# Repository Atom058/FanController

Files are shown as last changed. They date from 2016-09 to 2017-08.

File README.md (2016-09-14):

#About this project
This project aims to create a PC fan controller, based on the Arduino / Atmel frameworks.

#Fuse bits

Low:	0xF7
High:	0xD8
Ext:	0x04

#Pins with input/output

*) OCR0A: Fan1PWM
*) OCR0B: Fan2PWM
*) OCR1A: Fan3PWM
*) OCR1B: Fan4PWM
*) OCR2A: Fan5PWM
*) ADC0: FanCurrentSense1
*) ADC1: FanCurrentSense2
*) ADC2: FanCurrentSense3
*) ADC3: FanCurrentSense4
*) ADC4: FanCurrentSense5
*) PD0: SER
*) PD1: SRCLK
*) PD2: SRCLR
*) PD3: RCLK
*) PD4: OE
*) XTAL1: Crystal
*) XTAL2: Crystal
*) PB4: Switch Left
*) PB5: Switch Right
*) PB0: Switch press

##Unconnected pins
*) PC5
*) PD7

#Fuses

CKSEL0: 1
CKSEL1: 1
CKSEL2: 1
CKSEL3: 0

SUT0: 0
SUT1: 1

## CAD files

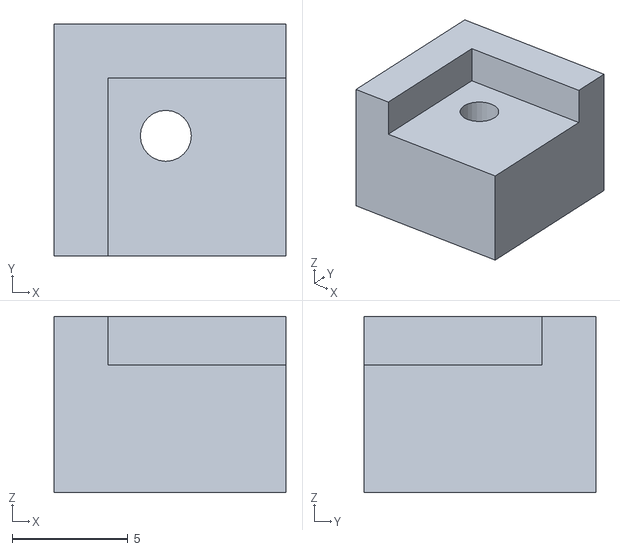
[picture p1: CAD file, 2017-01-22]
Fan controller schematics/3D drawing/Back support.stl
10.0 x 10.0 x 7.60

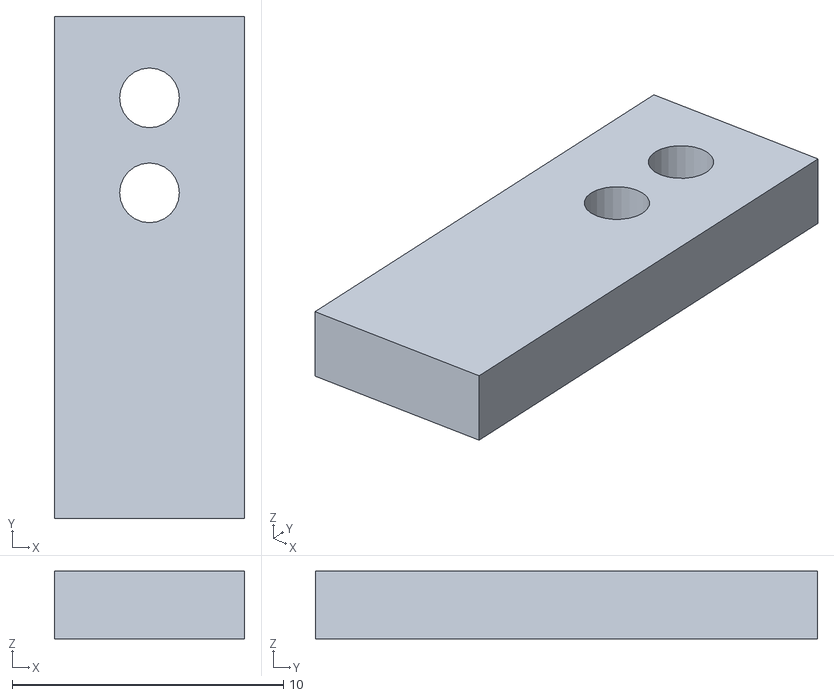
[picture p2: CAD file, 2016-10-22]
Fan controller schematics/3D drawing/Rotary Encoder - endstop attachement v1.stl
7.00 x 18.5 x 2.50

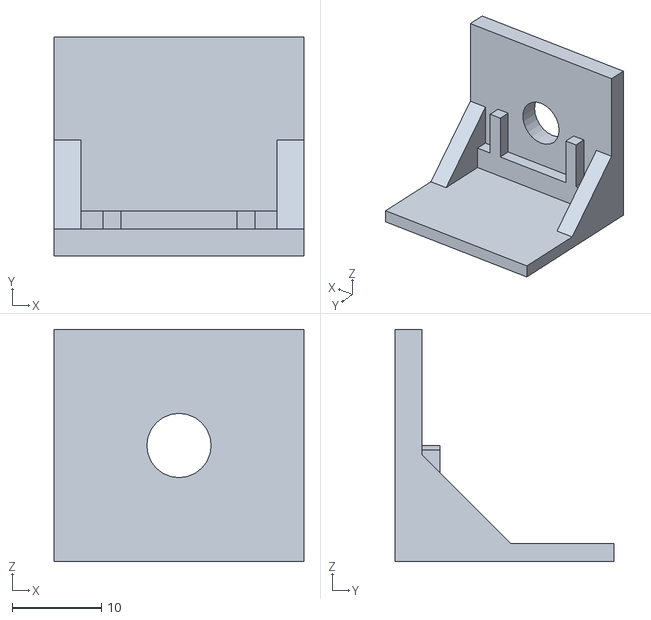
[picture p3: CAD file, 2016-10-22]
Fan controller schematics/3D drawing/Rotary Encoder - wagon v1.stl
28.0 x 24.5 x 26.0

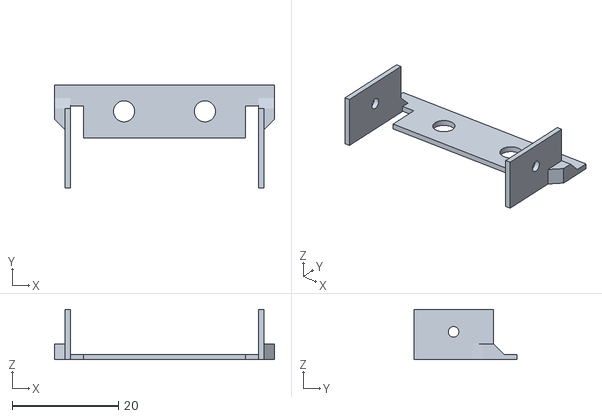
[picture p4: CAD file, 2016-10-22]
Fan controller schematics/3D drawing/Rotary encoder - click support B v1.stl
41.5 x 19.5 x 9.50

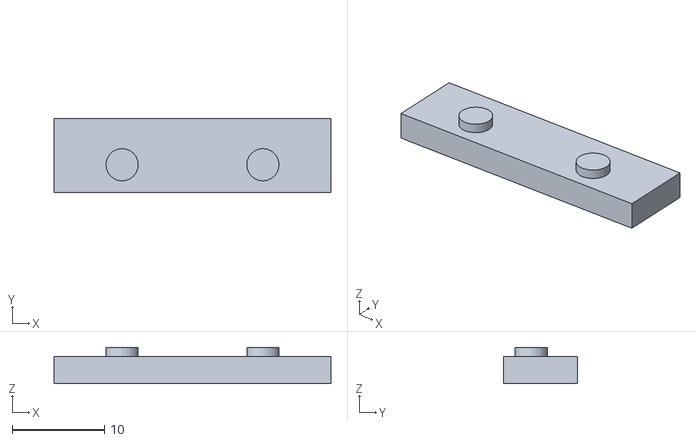
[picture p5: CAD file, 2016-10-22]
Fan controller schematics/3D drawing/Rotary encoder - click support A v1.stl
30.0 x 8.00 x 3.90

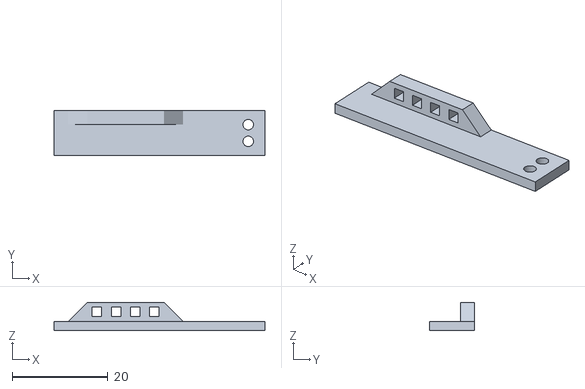
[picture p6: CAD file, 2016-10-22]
Fan controller schematics/3D drawing/Rotary Encoder - endstop v2.stl
44.1 x 9.50 x 5.90

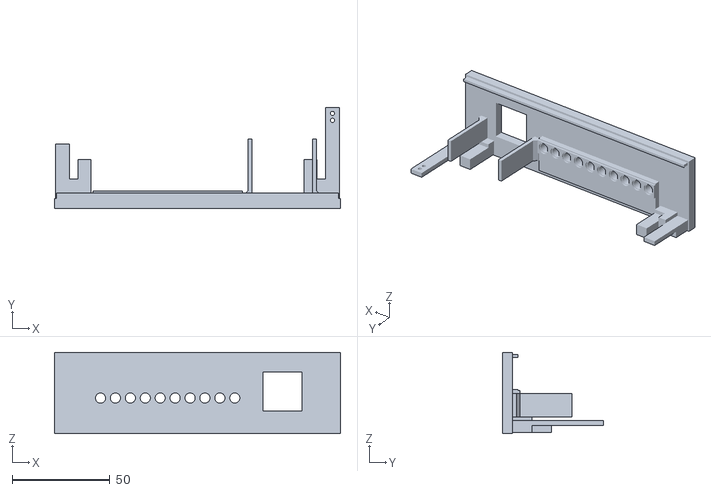
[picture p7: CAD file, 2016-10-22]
Fan controller schematics/3D drawing/Fan controller Front v1.stl
146.1 x 51.5 x 41.5

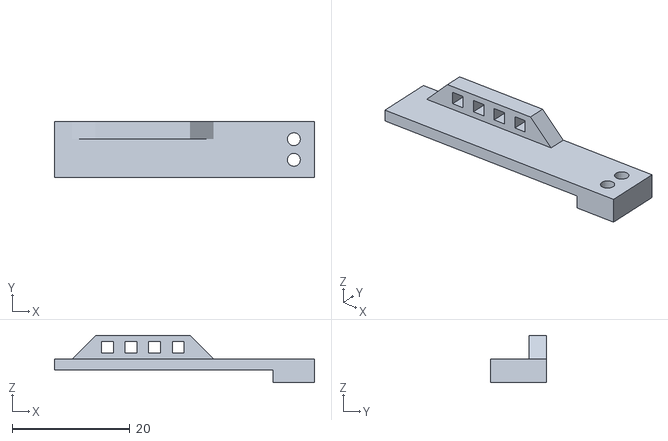
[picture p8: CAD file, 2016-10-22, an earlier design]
Fan controller schematics/3D drawing/Rotary Encoder - endstop v1.stl
44.1 x 9.50 x 8.00

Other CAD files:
Fan controller schematics/3D drawing/Fan Controller - V1.skp
Fan controller schematics/3D drawing/Fan Controller.skp

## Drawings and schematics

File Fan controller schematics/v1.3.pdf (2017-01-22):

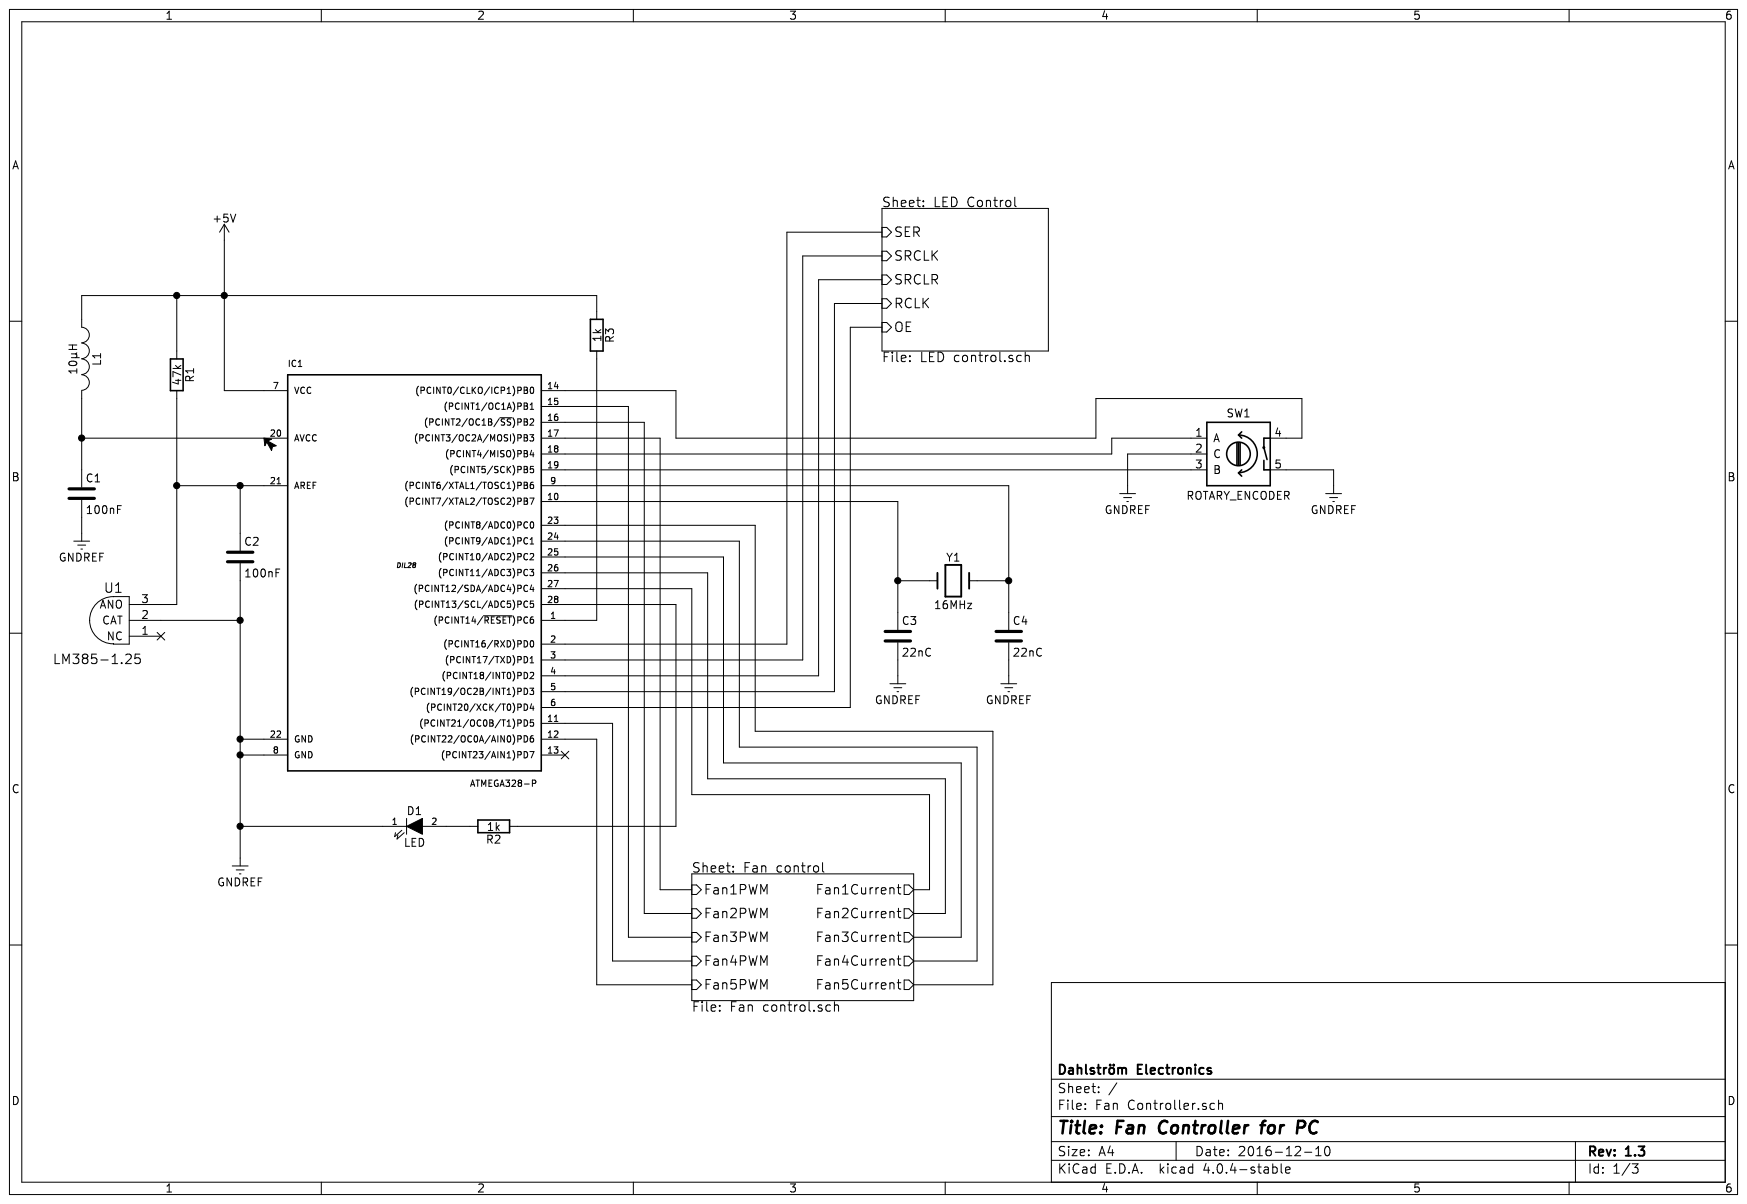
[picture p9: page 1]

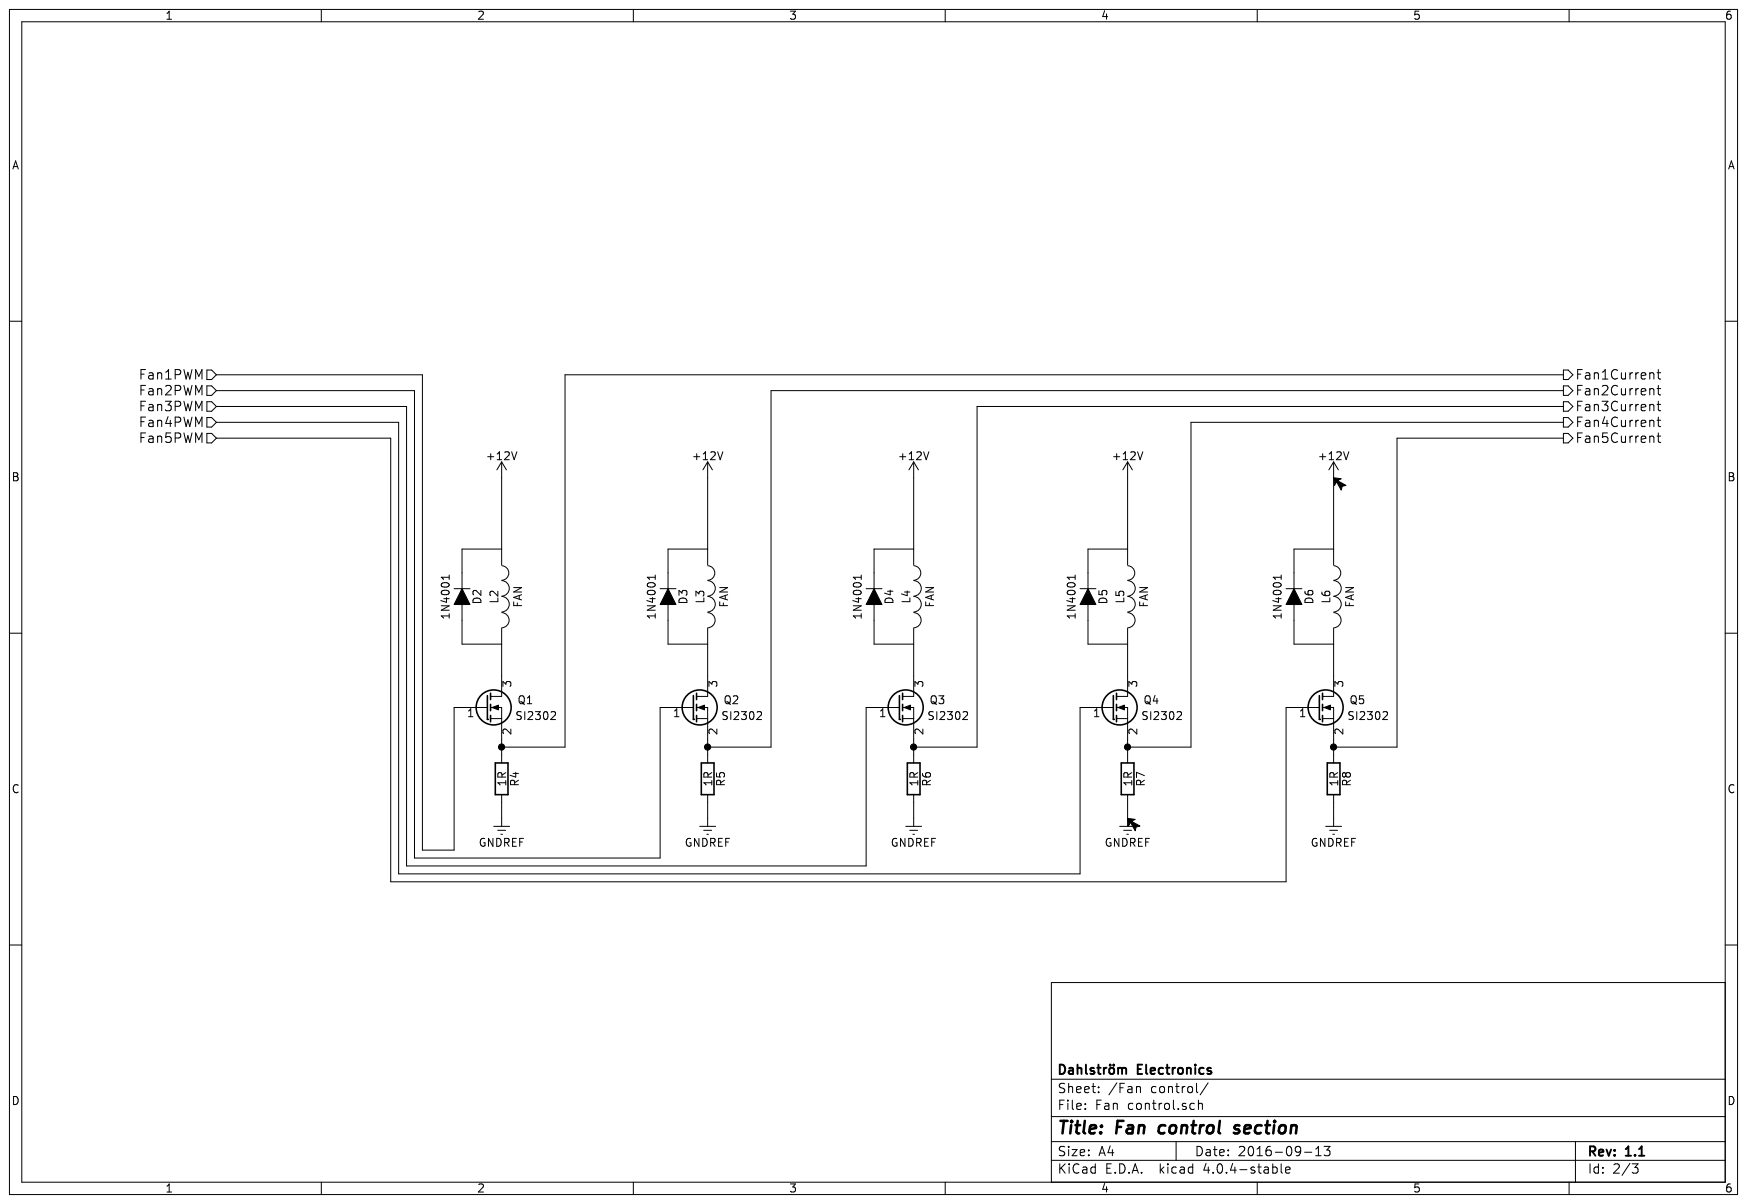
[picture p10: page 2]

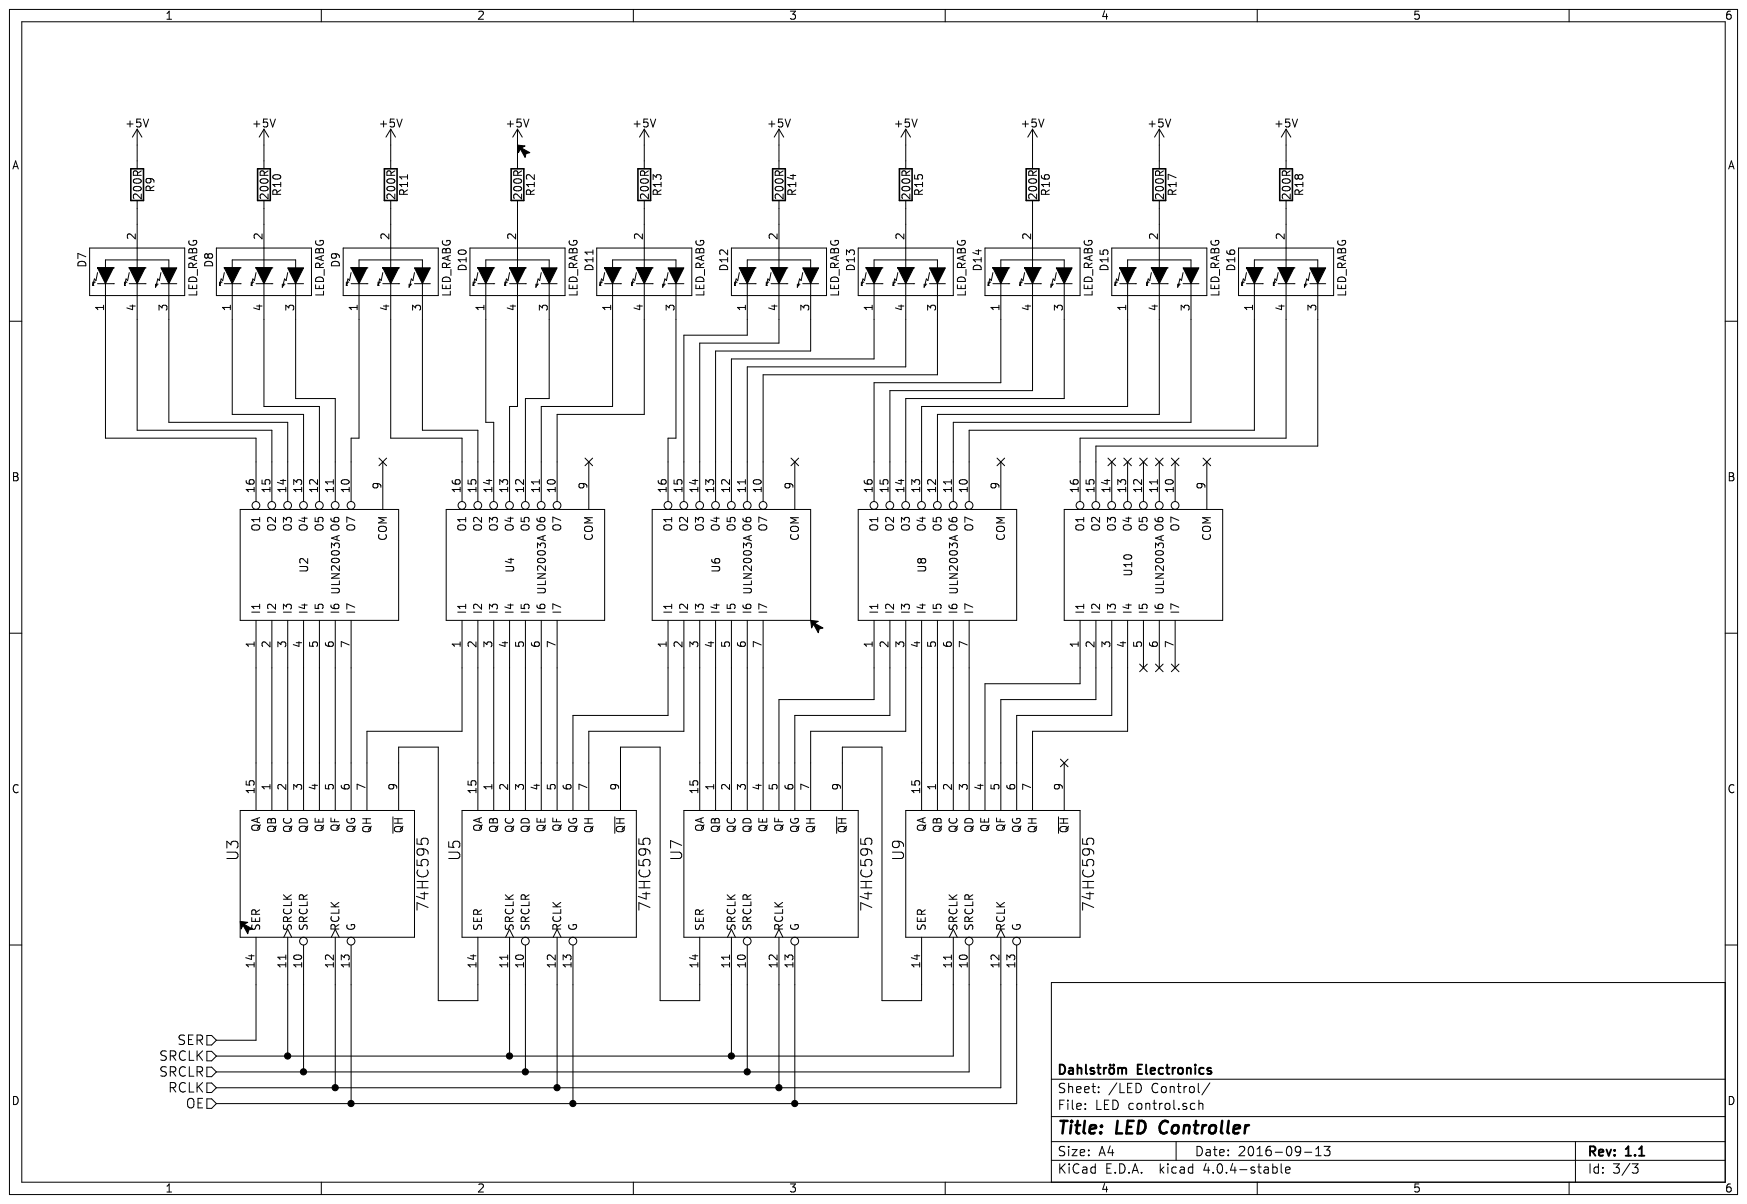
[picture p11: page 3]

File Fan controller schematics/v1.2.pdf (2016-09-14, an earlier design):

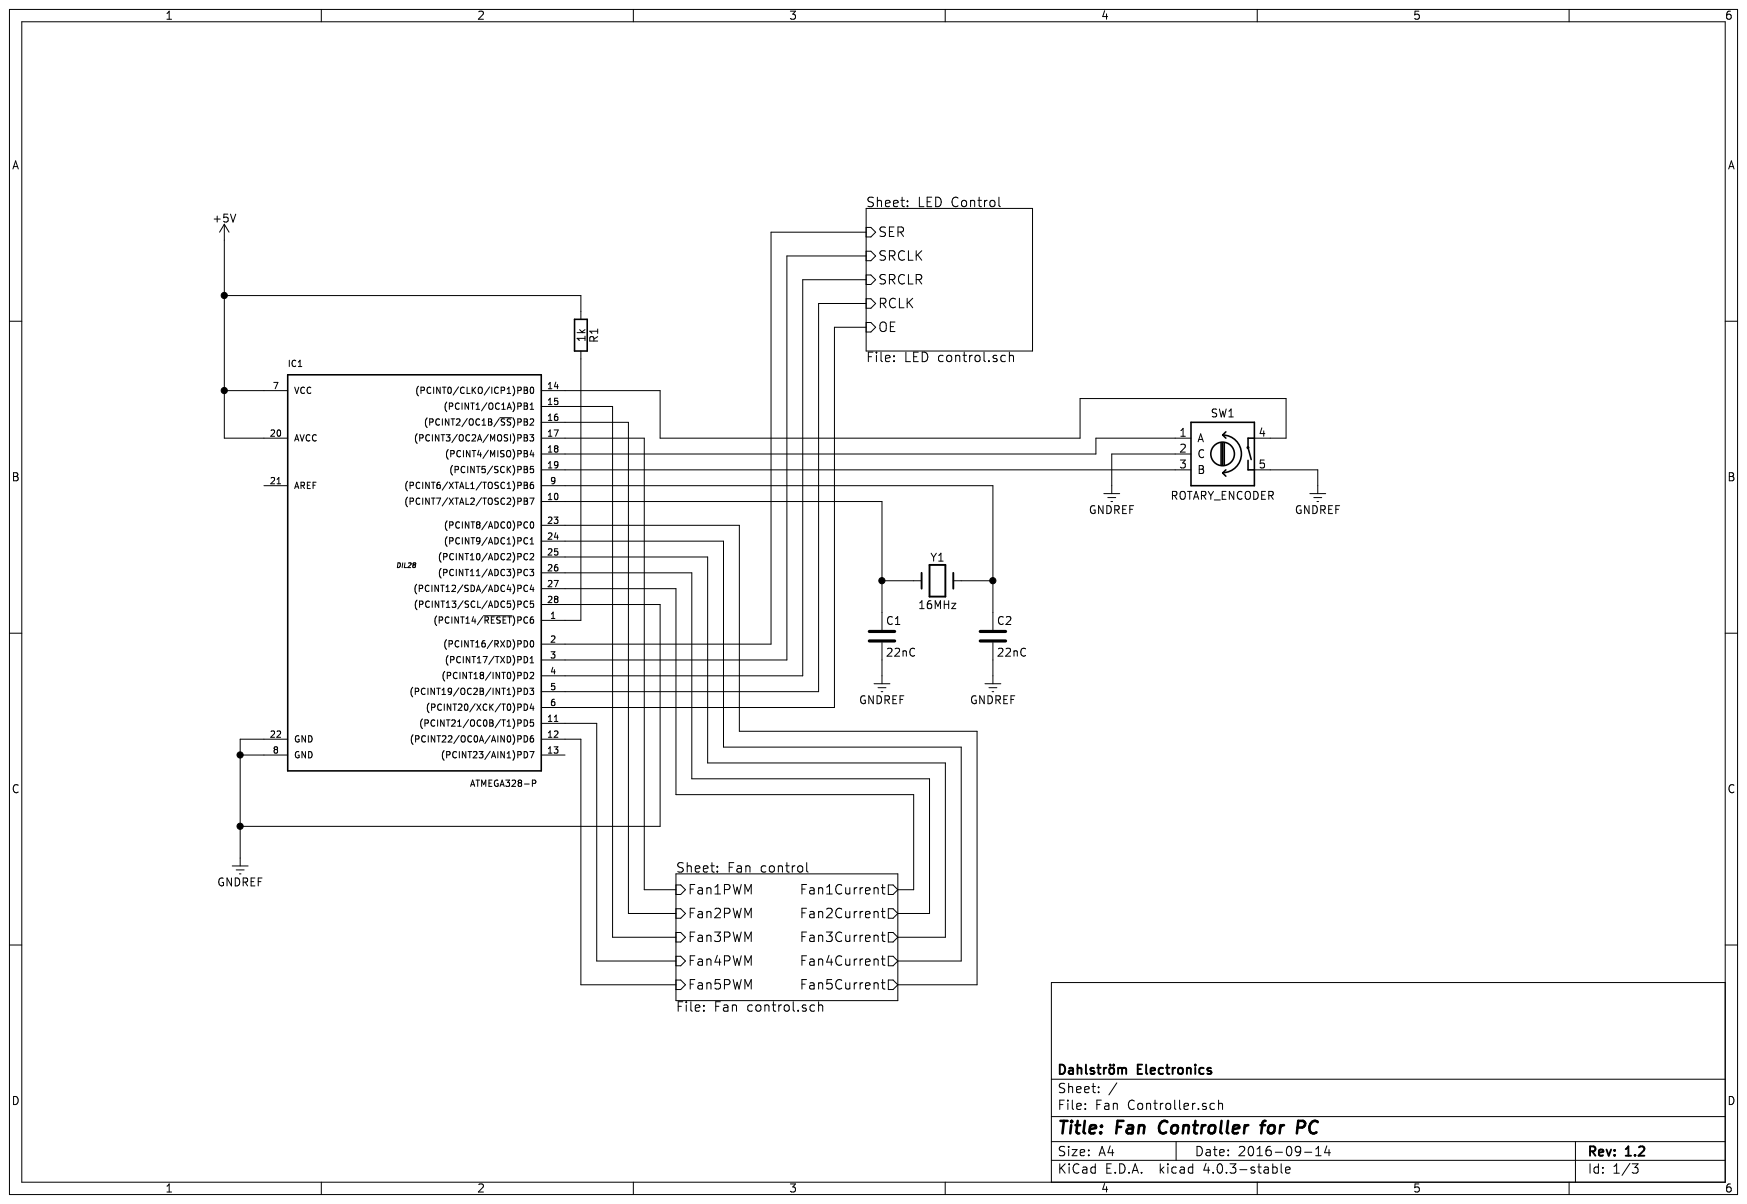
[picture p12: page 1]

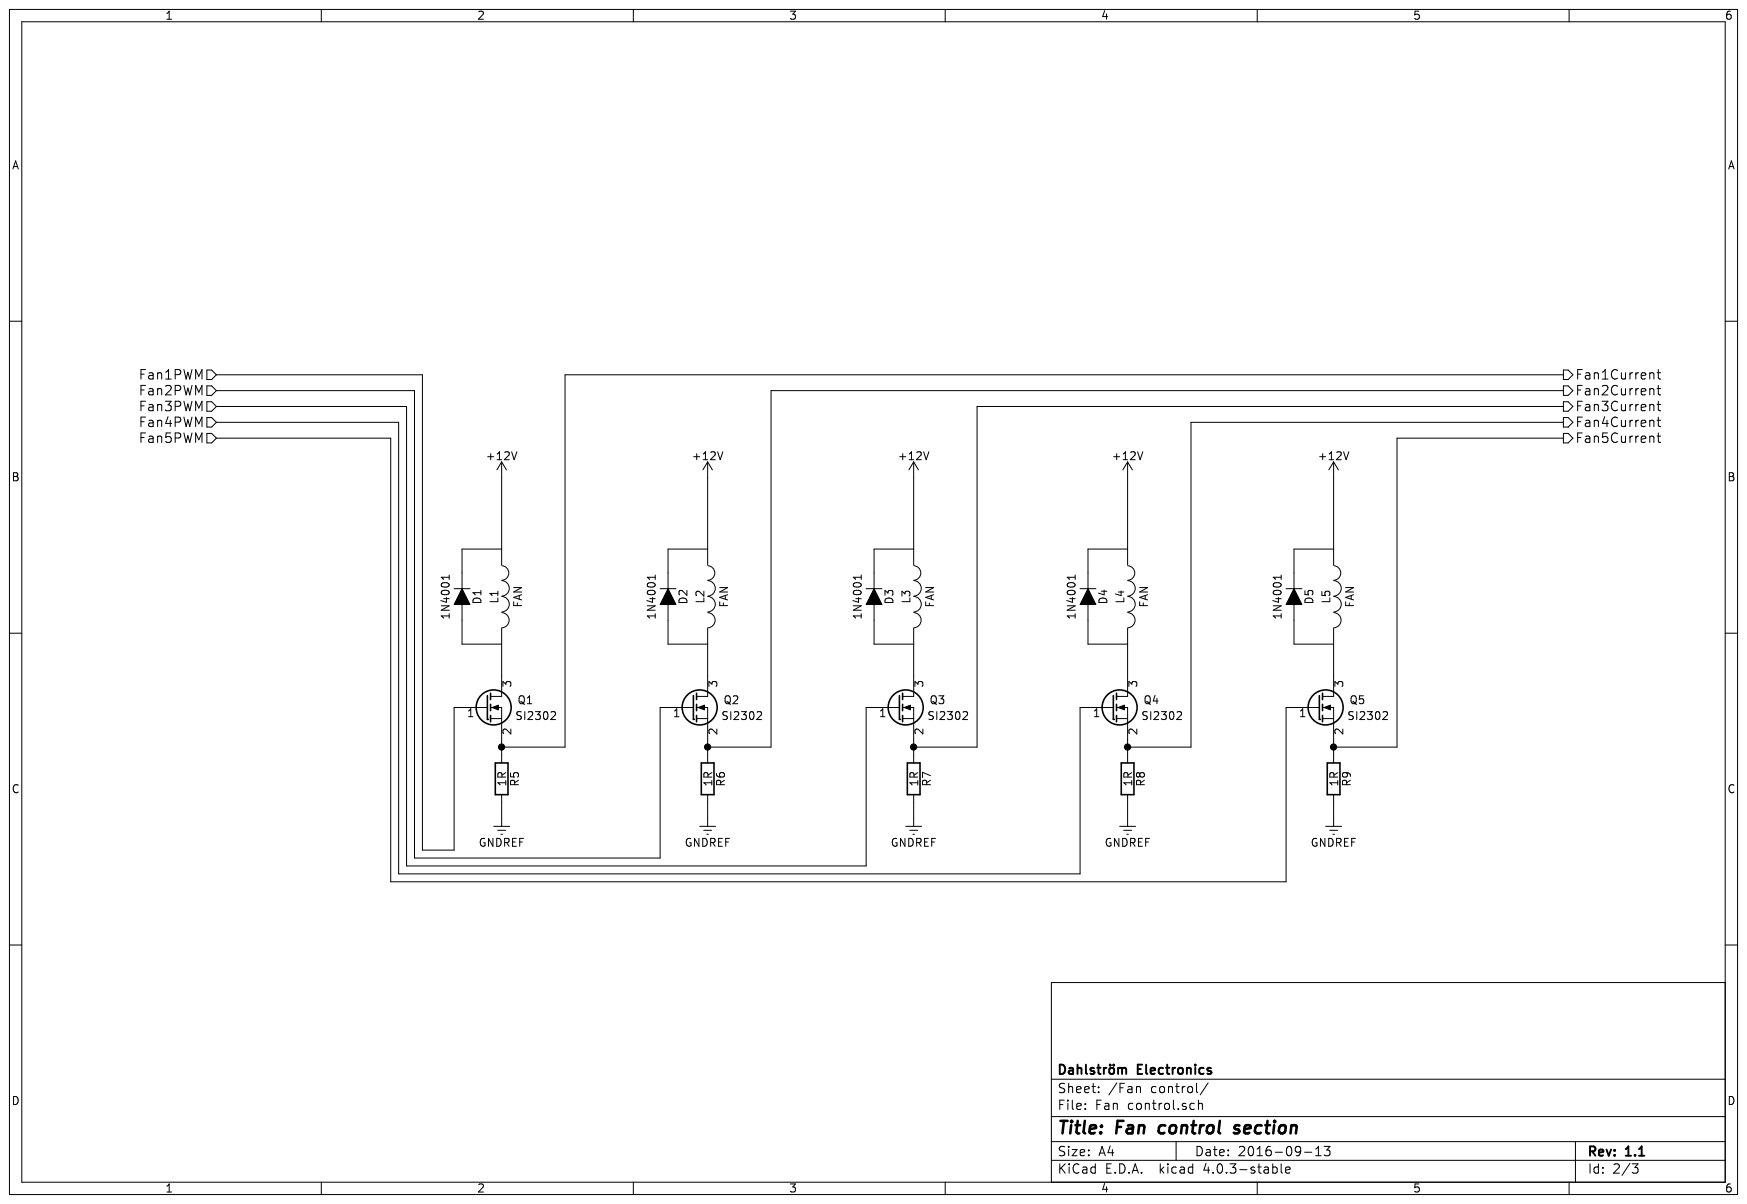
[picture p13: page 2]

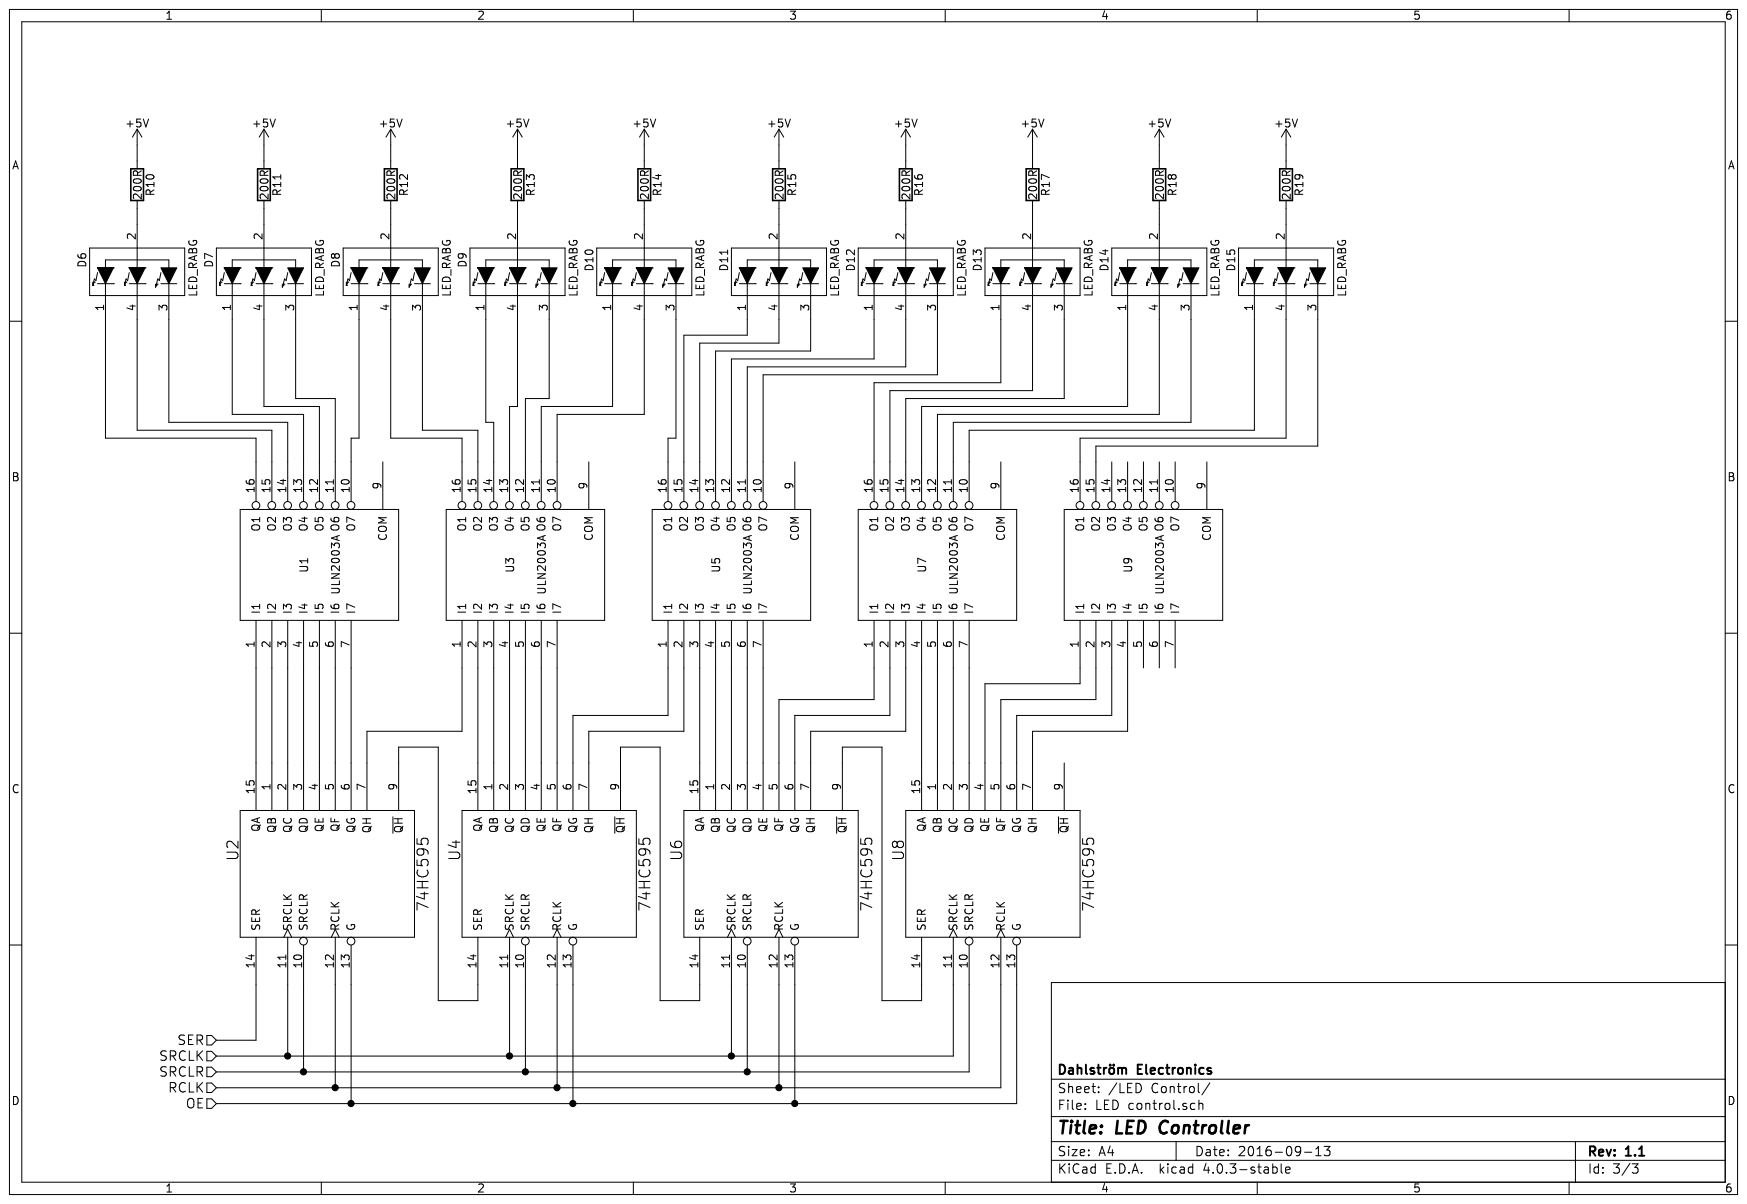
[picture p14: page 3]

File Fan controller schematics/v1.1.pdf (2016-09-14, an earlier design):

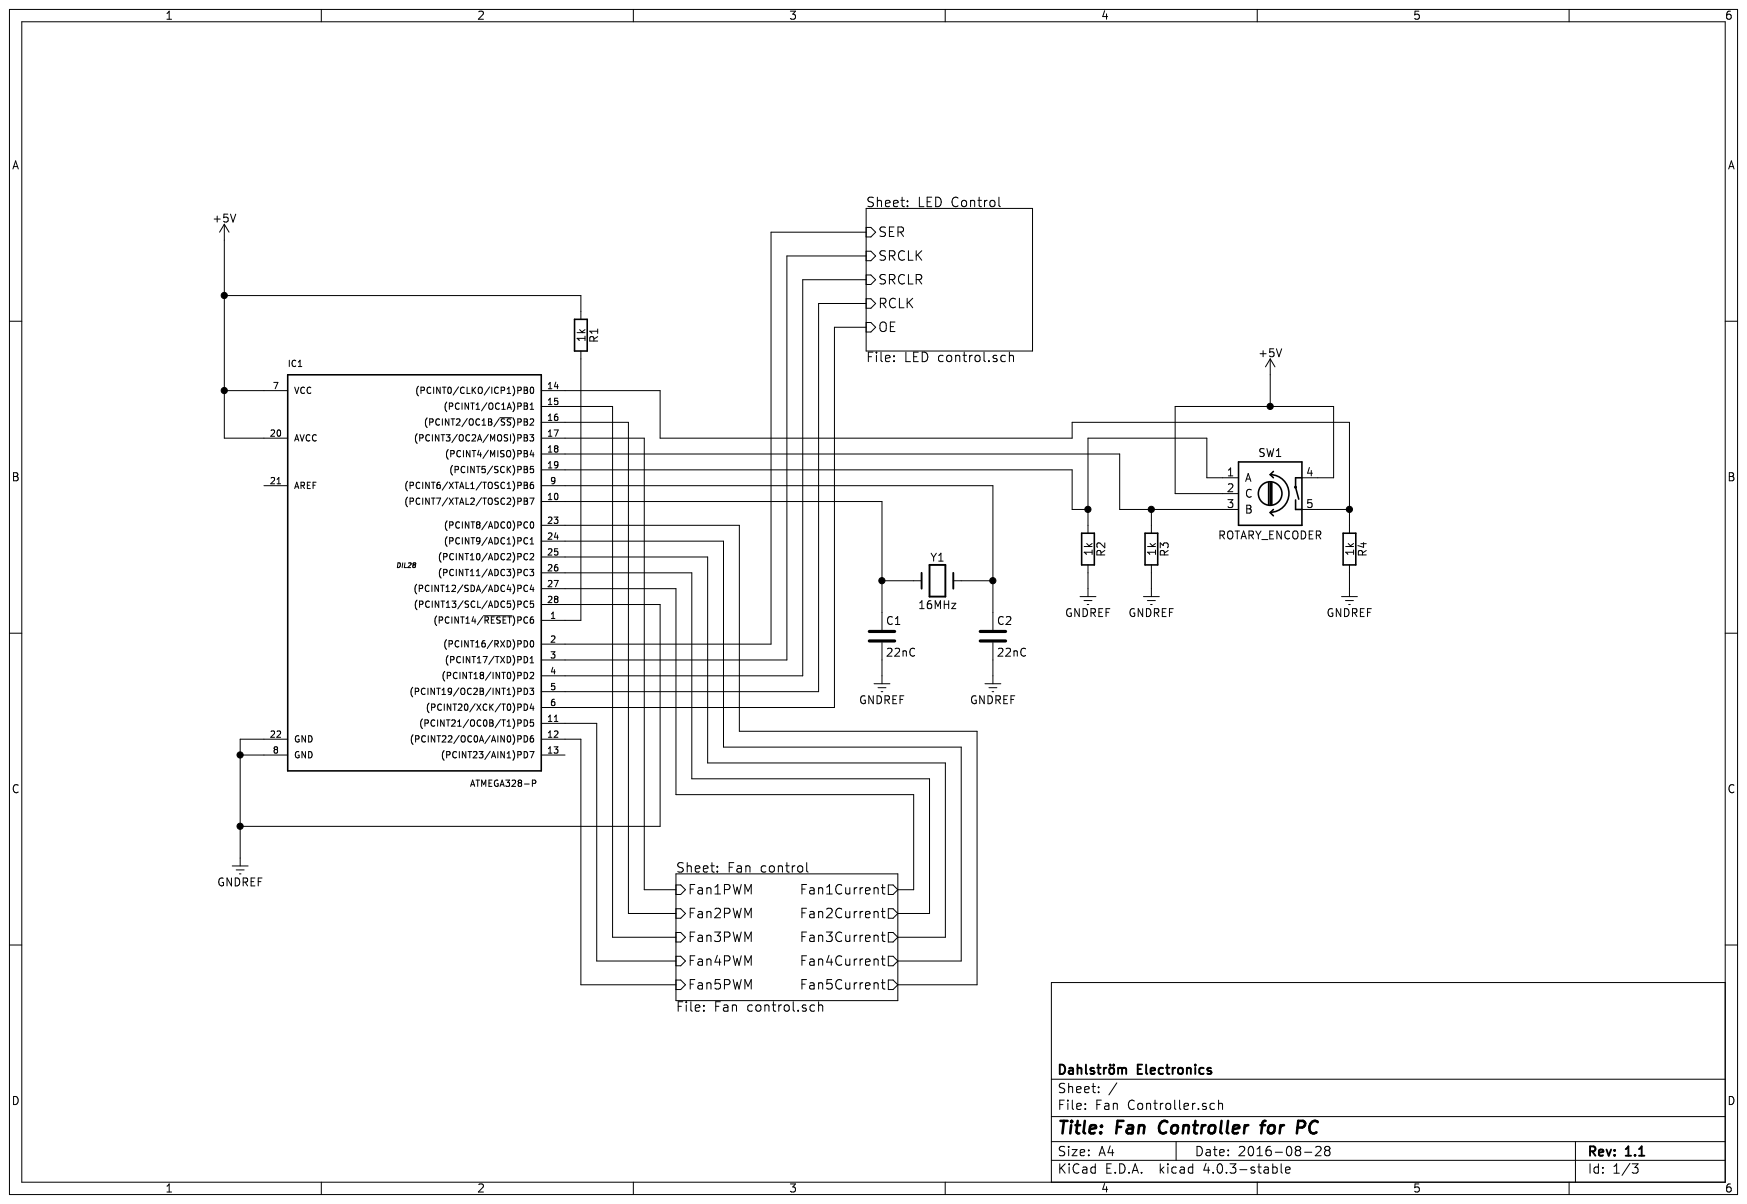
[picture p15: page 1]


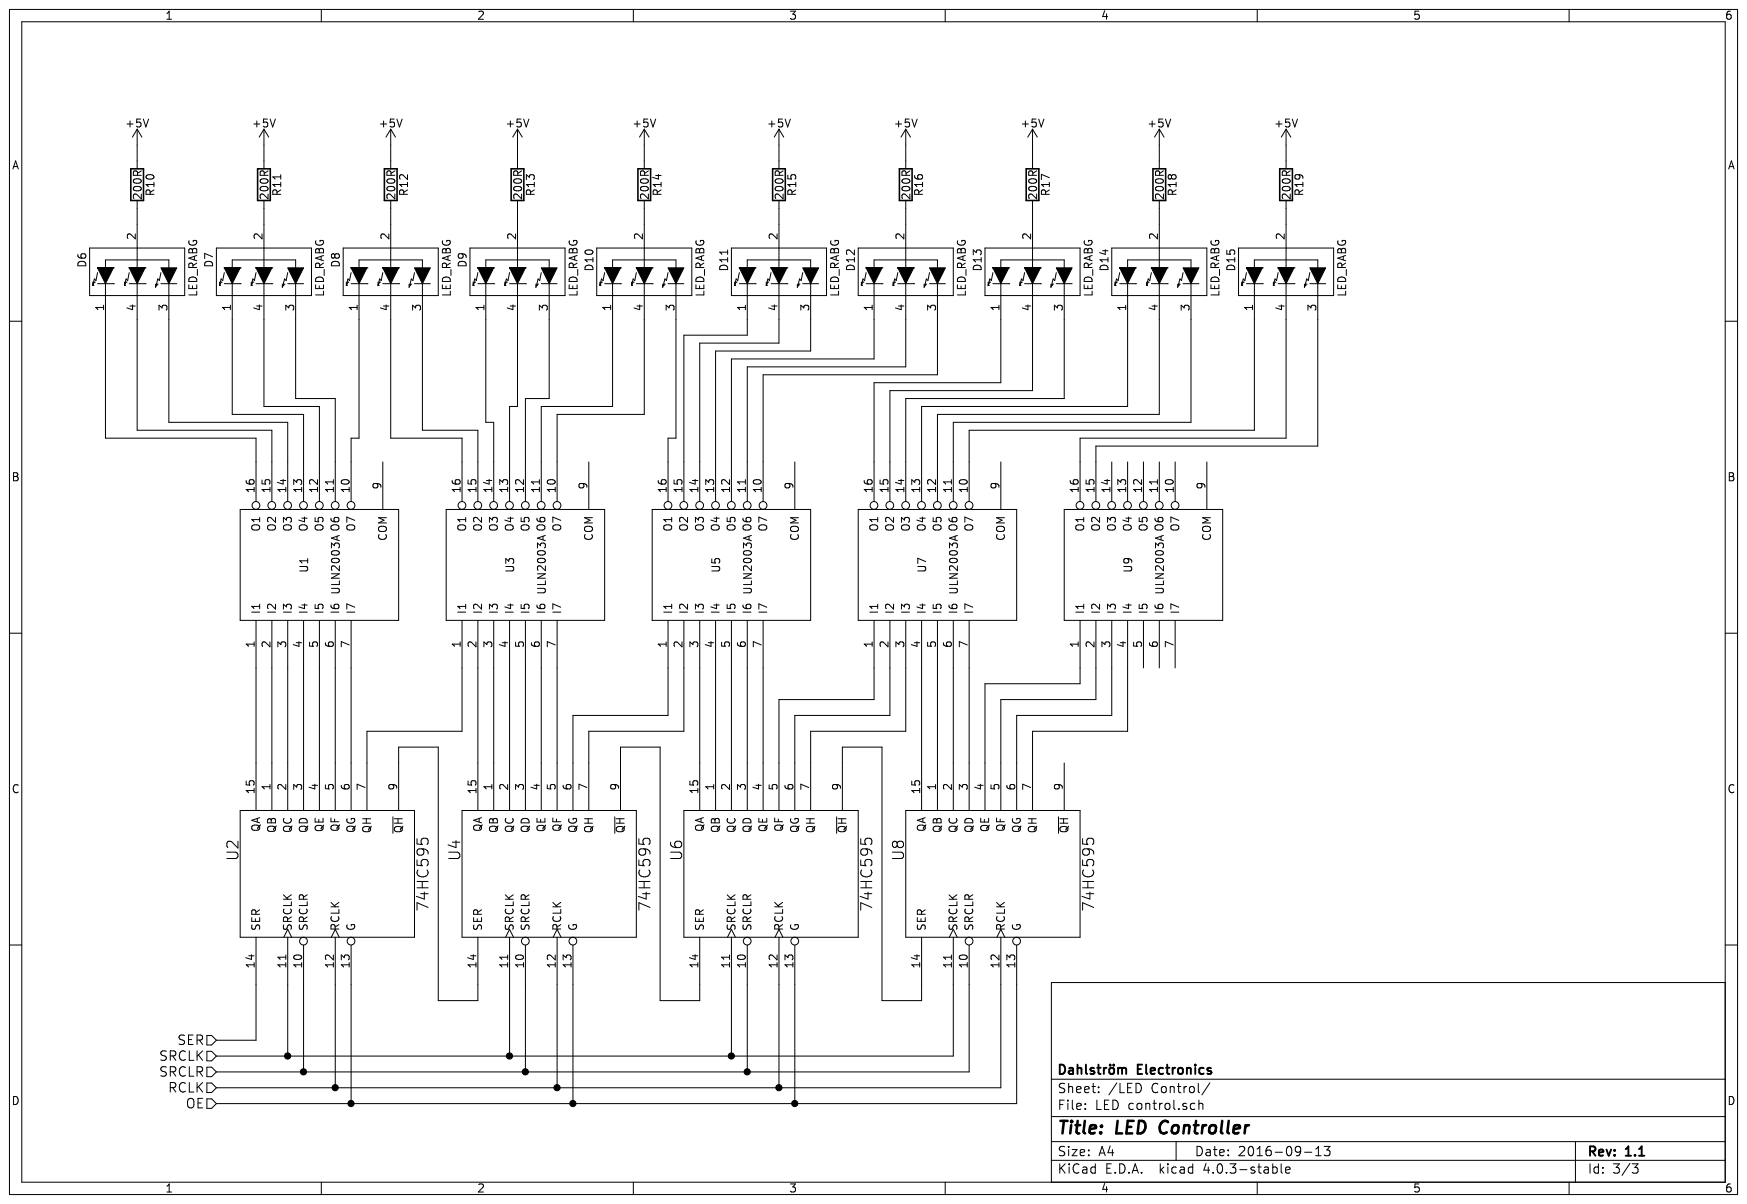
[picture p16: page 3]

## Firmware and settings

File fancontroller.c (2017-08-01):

#include <fancontroller.h>


//Input parsing
	//Timer unit, updated by WD timer approximately every 16ms
	uint16_t looptime = 0;
	uint16_t leftButtonTime = 0;
	uint16_t rightButtonTime = 0;
	uint16_t downButtonTime = 0;

	//These two variables uses the same bit locations (DOWN/LEFT/RIGHT)
	uint8_t buttonStatus = 0; //Button press status
	uint8_t inputUsed = 0; //Input used status (to avoid rogue triggering)
	uint8_t buttonStatusLogical = 0;

//Fan status
	uint16_t fan1Current = 0;
	uint16_t fan2Current = 0;
	uint16_t fan3Current = 0;
	uint16_t fan4Current = 0;
	uint16_t fan5Current = 0;

	uint16_t fan1CurrentMaxSpeed = 0;
	uint16_t fan2CurrentMaxSpeed = 0;
	uint16_t fan3CurrentMaxSpeed = 0;
	uint16_t fan4CurrentMaxSpeed = 0;
	uint16_t fan5CurrentMaxSpeed = 0;

	uint8_t connectedFans = 0;
	uint8_t currentProfile = HPROFILE;
	uint8_t fanProfileSpeeds[5][3] = {
		  {10, 10, 10}
		, {10, 10, 10}
		, {10, 10, 10}
		, {10, 10, 10}
		, {10, 10, 10}
	};

//LED display variables
	uint8_t currentChannel[10] = {0, 0, 0, 0, 0, 0, 0, 0, 0, 0};
	uint8_t	LEDColours[10][3] = {
			  {0, 0, 0}
			, {0, 0, 0}
			, {0, 0, 0}
			, {0, 0, 0}
			, {0, 0, 0}
			, {0, 0, 0}
			, {0, 0, 0}
			, {0, 0, 0}
			, {0, 0, 0}
			, {0, 0, 0}
		}; //Array holding current colour of all LED's, as well as a dimmer channel
	uint8_t	buffer[10][3] = {
			  {0, 0, 0}
			, {0, 0, 0}
			, {0, 0, 0}
			, {0, 0, 0}
			, {0, 0, 0}
			, {0, 0, 0}
			, {0, 0, 0}
			, {0, 0, 0}
			, {0, 0, 0}
			, {0, 0, 0}
		}; //Array holding current colour of all LED's, used in sweeping the LED's

	//Map of linear intensities to Gamma-corrected values
	uint8_t gammaMap[8] = {0, 2, 4, 5, 6, 7};

//Interface status
	uint8_t currentView = VIEWSTART;
	uint8_t cursorPosition = LED01;

	uint8_t adjustFAN = FAN1; //For the view setting fan-speed
	uint8_t adjustColourType = PRIMARYCOLOUR; //For the view setting LED colour
	uint8_t adjustColourCh = RCH; //For the view setting LED colour

	//Default colour settings
	uint8_t noColour[3] = {0, 0, 0};
	uint8_t primaryColour[3] = {5, 0, 0};
	uint8_t complementColour[3] = {0, 5, 0};
	uint8_t selectColour[3] = {0, 0, 5};

int main (void) {

	cli();
	setup(); //Set up arduino
	startup(); //Initiate fan controller
	sei();

	while(1){

		if(DEBUGDISPLAY){
			debuginputController();
		} else{
			parseInput();
		}
	} //while

}

void setup(void) {

	//cli(); //Disable interrupts temoprarily

		//Set prescaler to 1 (16MHz)
			CLKPR = _BV(CLKPCE);
			CLKPR = 0;

		//Timer 0-2 for PWM
			//Configure pins as outputs
			DDRD |= _BV(DDD5) | _BV(DDD6);
			DDRB |= _BV(DDB1) | _BV(DDB2) | _BV(DDB3);

			//Set prescalers to 1/256 of I/O clock
			TCCR0B |= _BV(CS02); //Timer0 Prescaler
			TCCR1B |= _BV(CS12); //Timer1 Prescaler
			TCCR2B |= _BV(CS22) | _BV(CS21); //Timer2 Prescaler

			//Set fast-PWM mode
				//Timer0 PWM settings
				TCCR0A |= _BV(COM0A1) | _BV(COM0B1) | _BV(WGM00) | _BV(WGM01); 
				//Timer1 PWM settings - 8BIT timer mode
				TCCR1A |= _BV(COM1A1) | _BV(COM1B1) | _BV(WGM10);
				TCCR1B |= _BV(WGM12);
				//Timer2 PWM settings (only OC2A used as output)
				TCCR2A |= _BV(COM2A1) | _BV(WGM20) | _BV(WGM21);
			
			//Enable interrupt for Timer2 overflow and half way (used for LED updates)
				OCR2B = 128; //Half way point
				TIMSK2 |= _BV(TOIE2) | _BV(OCIE2B); //Enable interrupts for overflow and halfway

		//Set inputs for rotary encoder - all inputs with pull-ups
			//PB0/P14 button, PB4/P18 Left. PB5/P19 Right
			PORTB |= _BV(PORTB0) | _BV(PORTB4) | _BV(PORTB5); //Activate pullups
			//Enable interrupts for inputs
			PCICR |= _BV(PCIE2) | _BV(PCIE1); //Interrupts enabled for ports 8-14 & 16-23
			PCMSK2 |= _BV(PCINT19) | _BV(PCINT18); //Interrupts for pin 18 and 19
			PCMSK1 |= _BV(PCINT14); //Interrupts for pin 14

		//Enable watchdog timer -- useful for time-keeping
			MCUSR &= ~(_BV(WDRF)); //Reset WD interrupt
			WDTCSR |= _BV(WDCE) | _BV(WDE); //Unlock WD setting
			WDTCSR = 0x00; //Clear WDE, and set new prescaler to 0-0-0-0, i.e. 16ms
			WDTCSR |= WDIE; //Enable WD interrupt mode
			
		//Set Outputs for shift register
			DDRD |= _BV(DDD0) |	_BV(DDD1) |	_BV(DDD2) |	_BV(DDD3) |	_BV(DDD4);
			PORTD |= _BV(PORTD2); //avoid clear!
			PORTD &= ~(_BV(PORTD4)); //Enable output

		//Disable pin 28 / PC6 by enabling internal pull-up (in input configuration)
			DDRC |= _BV(DDC5); //Currently used as power on signal, as well as diagnostics
			PORTC |= _BV(PORTC5);
		//Disable pin 13 by enabling internal pull-up
			PORTD |= _BV(PORTD7);

		//ADC configuration
			//ADMUX: REFS1 & REFS0 set to 0 as standard, so external AREF pin is used as reference
			ADCSRA |= _BV(ADPS0) | _BV(ADPS1) | _BV(ADPS2); //Set prescaler to 128 (125 kHz)
			ADCSRA |= _BV(ADEN); //Enable ADC
			ADCSRA |= _BV(ADSC); //Make an empty conversion to initiate ADC
			while(ADCSRA>>ADSC & 1); //Wait until conversion is finished

			//Disable digital inputs on Analog pins
			DIDR0 |= _BV(ADC0D) | _BV(ADC1D) | _BV(ADC2D) | _BV(ADC3D) | _BV(ADC4D);

	//sei(); //Enable interrupts again

}

/*
	Startup routine
		Sets all fans to 100% in order to ensure adequate startup power
		Records the fans current consumption at 100% speed
		Stores connection status
*/
void startup(void) {

	//Activate all fans on full speed
	OCR0A = ~(0); //Fan #1
	OCR0B = ~(0); //Fan #2
	OCR1AL = ~(0); //Fan #3
	OCR1BL = ~(0); //Fan #4
	OCR2A = ~(0); //Fan #5

	//Let the fans spin to full speed

	//Blinking status light
	uint8_t time = STARTUPFANWARMINGINDICATORINTERVAL;

	for(int i=0; i<=STARTUPFANWARMINGPERIOD;){

		PORTC ^= _BV(PORTC5);
		_delay_ms(time); 
		i += time;

	}

	//Store connection status
	checkConnections();

	PORTC &= ~(_BV(PORTC5)); //Ensure that the LED is off

	//Initiate interface for start view
	updateInterface();

}

/* ------------------------

[Controller functions]

--------------------------- */
void parseInput(void){

	/*
		if we have any inputs, pipe to relevant controller
		Button presses might carry over between controller transitions,
		so we should remove already used inputs from the pool.

		TODO: long presses?
	*/
	buttonStatusLogical = buttonStatus ^ inputUsed;

	if(buttonStatusLogical){
		
		if(DEBUGINPUT){
			debuginputController();
		} else {
			
			switch(currentView){
		
				case VIEWSTART:
					startController();
					break;
				case VIEWSETTINGS:
					settingsController();
					break;
				case VIEWSETFAN:
					setfanController();
					break;
				case VIEWCOLOUROVERVIEW:
					colouroverviewController();
					break;
				case VIEWCOLOURSETTING:
					coloursettingController();
					break;
				case VIEWCOLOURCHANNELSETTING:
					colourchannelsettingController();
					break;
		
			} //switch

			/*
			Controllers will initiate the transition to any next screens by
			setting the currentView variable. As controllers are only responsible
			for updating the view if there is an input, we display the default
			views initially.
			*/
			updateInterface();

		}

	}//if

	//Special case for accessing the calibration of colours
	else if ((buttonStatus>>DOWN & 1) && looptime - downButtonTime > LONGPRESSFORCOLOURDELAY){
		currentView = VIEWCOLOUROVERVIEW;
		updateInterface();
	}

}

// ----- start of controllers ----- //
void startController(void){

	if(buttonStatusLogical>>DOWN & 1){

		//Pressing button should get us to next screen
		//Update cursor position, as this will dictate start location!
		cursorPosition = CURSORUNDETERMINED;
		
		currentView = VIEWSETTINGS;
		inputUsed |= 1<<DOWN;

	}

}

void settingsController(void){

	if(cursorPosition == CURSORUNDETERMINED){
		
		switch (currentProfile){

			case LPROFILE:
				cursorPosition = LED07;
				break;

			case MPROFILE:
				cursorPosition = LED08;
				break;

			case HPROFILE:
				cursorPosition = LED09;
				break;

		}

	}

	if(buttonStatusLogical>>DOWN & 1){

		switch (cursorPosition){

			//Fans
			case LED01:
				adjustFAN = FAN1;
				currentView = VIEWSETFAN;
				break;

			case LED02:
				adjustFAN = FAN2;
				currentView = VIEWSETFAN;
				break;

			case LED03:
				adjustFAN = FAN3;
				currentView = VIEWSETFAN;
				break;

			case LED04:
				adjustFAN = FAN4;
				currentView = VIEWSETFAN;
				break;

			case LED05:
				adjustFAN = FAN5;
				currentView = VIEWSETFAN;
				break;

			case LED07:
				currentProfile = LPROFILE;
				currentView = VIEWSTART;
				break;

			case LED08:
				currentProfile = MPROFILE;
				currentView = VIEWSTART;
				break;

			case LED09:
				currentProfile = HPROFILE;
				currentView = VIEWSTART;
				break;

			case LED10:
				currentView = VIEWSTART;
				break;

		}

		inputUsed |= 1<<DOWN;
		cursorPosition = CURSORUNDETERMINED;
		

	} else if(buttonStatusLogical>>LEFT & 1){

		if(cursorPosition < LED01){

			cursorPosition++;

			if(cursorPosition == LED06)
				cursorPosition++;

		} else {
			cursorPosition = LED01;
		}

		inputUsed |= 1<<LEFT;

	} else if(buttonStatusLogical>>RIGHT & 1){

		if(cursorPosition > LED10){

			cursorPosition--;

			if(cursorPosition == LED06)
				cursorPosition--;

		} else {
			cursorPosition = LED10;
		}

		inputUsed |= 1<<RIGHT;

	}

}

void setfanController(void){

	// Cursor not needed?: if(cursorPosition == CURSORUNDETERMINED)

	if(buttonStatusLogical>>DOWN & 1){

		cursorPosition = CURSORUNDETERMINED;
		currentView = VIEWSETTINGS;

		//TODO: SAVE TO EEPROM!

		inputUsed |= 1<<DOWN;

	} else if(buttonStatusLogical>>LEFT & 1){

		if(fanProfileSpeeds[adjustFAN][currentProfile] > 0){
			fanProfileSpeeds[adjustFAN][cursorPosition]--;
		} else {
			fanProfileSpeeds[adjustFAN][cursorPosition] = 0;
		}

		inputUsed |= 1<<LEFT;

	} else if(buttonStatusLogical>>RIGHT & 1){
		
		if(fanProfileSpeeds[adjustFAN][currentProfile] < 10){
			fanProfileSpeeds[adjustFAN][currentProfile]++;
		} else {
			fanProfileSpeeds[adjustFAN][currentProfile] = 10;
		}

		inputUsed |= 1<<RIGHT;

	}

}

void colouroverviewController(void){

	if(cursorPosition == CURSORUNDETERMINED)
		cursorPosition = LED02;

	if(buttonStatusLogical>>DOWN & 1){

		switch(cursorPosition) {

			case LED02:
			//Primary colour
				currentView = VIEWCOLOURSETTING;
				adjustColourType = PRIMARYCOLOUR;
				break;

			case LED05:
			//Complement colour
				currentView = VIEWCOLOURSETTING;
				adjustColourType = COMPLEMENTCOLOUR;
				break;

			case LED08:
			//Select colour
				currentView = VIEWCOLOURSETTING;
				adjustColourType = SELECTCOLOUR;
				break;

			case LED10:
			//Enter-exit to home
				currentView = VIEWSTART;
				break;

		}

		cursorPosition = CURSORUNDETERMINED;
		inputUsed |= 1<<DOWN;

	} else if(buttonStatusLogical>>LEFT & 1){

		switch (cursorPosition){
			
			case LED02:
				cursorPosition = LED02;
				break;

			case LED05:
				cursorPosition = LED02;
				break;

			case LED08:
				cursorPosition = LED05;
				break;

			case LED10:
				cursorPosition = LED08;
				break;

		}

		inputUsed |= 1<<LEFT;

	} else if(buttonStatusLogical>>RIGHT & 1){
		
		switch (cursorPosition){
			
			case LED02:
				cursorPosition = LED05;
				break;

			case LED05:
				cursorPosition = LED08;
				break;

			case LED08:
				cursorPosition = LED10;
				break;

			case LED10:
				cursorPosition = LED10;
				break;

		}

		inputUsed |= 1<<RIGHT;

	}

}

void coloursettingController(void){

	if(cursorPosition == CURSORUNDETERMINED)
		cursorPosition = LED02; //RED

	if(buttonStatusLogical>>DOWN & 1){

		switch(cursorPosition) {

			case LED02:
				adjustColourCh = RCH;
				currentView = VIEWCOLOURCHANNELSETTING;
				break;

			case LED04:
				adjustColourCh = GCH;
				currentView = VIEWCOLOURCHANNELSETTING;
				break;

			case LED06:
				adjustColourCh = BCH;
				currentView = VIEWCOLOURCHANNELSETTING;
				break;

			case LED10:
				currentView = VIEWCOLOUROVERVIEW;
				break;

		}

		cursorPosition = CURSORUNDETERMINED;
		inputUsed |= 1<<DOWN;

	} else if(buttonStatusLogical>>LEFT & 1){

		switch (cursorPosition){
			
			case LED02:
				cursorPosition = LED02;
				break;

			case LED04:
				cursorPosition = LED02;
				break;

			case LED06:
				cursorPosition = LED04;
				break;

			case LED10:
				cursorPosition = LED06;
				break;

		}

		inputUsed |= 1<<LEFT;

	} else if(buttonStatusLogical>>RIGHT & 1){
		
		switch (cursorPosition){
			
			case LED02:
				cursorPosition = LED04;
				break;

			case LED04:
				cursorPosition = LED06;
				break;

			case LED06:
				cursorPosition = LED10;
				break;

			case LED10:
				cursorPosition = LED10;
				break;

		}

		inputUsed |= 1<<RIGHT;

	}

}

void colourchannelsettingController(void){

	if(buttonStatusLogical>>DOWN & 1){

		//Pressing down in any position works

		cursorPosition = CURSORUNDETERMINED;
		
		//TODO: Save to EEPROM

		currentView = VIEWCOLOURSETTING;

		inputUsed |= 1<<DOWN;

	} else if(buttonStatusLogical>>LEFT & 1){

		switch(adjustColourType){

			case PRIMARYCOLOUR:
				if(primaryColour[adjustColourCh] > 0){
					primaryColour[adjustColourCh]--;
				}
				break;

			case COMPLEMENTCOLOUR:
				if(complementColour[adjustColourCh] > 0){
					complementColour[adjustColourCh]--;
				}
				break;

			case SELECTCOLOUR:
				if(selectColour[adjustColourCh] > 0){
					selectColour[adjustColourCh]--;
				}
				break;


		}

		inputUsed |= 1<<LEFT;

	} else if(buttonStatusLogical>>RIGHT & 1){

		switch(adjustColourType){

			case PRIMARYCOLOUR:
				if(primaryColour[adjustColourCh] < MAXCHANNELVALUE){
					primaryColour[adjustColourCh]++;
				}
				break;

			case COMPLEMENTCOLOUR:
				if(complementColour[adjustColourCh] < MAXCHANNELVALUE){
					complementColour[adjustColourCh]++;
				}
				break;

			case SELECTCOLOUR:
				if(selectColour[adjustColourCh] < MAXCHANNELVALUE){
					selectColour[adjustColourCh]++;
				}
				break;


		}

		inputUsed |= 1<<RIGHT;
		
	}

}



/* ------------------------

[Fan functions]

--------------------------- */


/*
	Helper method to read and return a voltage for a sepcific fan
	Fan channels are recorded in macros FANxCH in .h file for easy reference
*/
uint16_t readFanCurrent(uint8_t chADC) {

	//Adjust analog channel in ADMUX
	switch(chADC) {

		case FAN1CH:
			//ADC0
			ADMUX &= ~(_BV(MUX3) | _BV(MUX2) | _BV(MUX1) | _BV(MUX0));
			break;
		
		case FAN2CH:
			//ADC1
			ADMUX &= ~(_BV(MUX3) | _BV(MUX2) | _BV(MUX1)); 
			ADMUX |= _BV(MUX0);
			break;
		
		case FAN3CH:
			//ADC2
			ADMUX &= ~(_BV(MUX3) | _BV(MUX2) | _BV(MUX0));
			ADMUX |= _BV(MUX1);
			break;
		
		case FAN4CH:
			//ADC3
			ADMUX &= ~(_BV(MUX3) | _BV(MUX2));
			ADMUX |= _BV(MUX1) | _BV(MUX0);
			break;
		
		case FAN5CH:
			//ADC4
			ADMUX &= ~(_BV(MUX3) | _BV(MUX1) | _BV(MUX0));
			ADMUX |= _BV(MUX2);
			break;

	}

	ADCSRA |=_BV(ADSC); //Starts conversion

	while( ADCSRA>>ADSC & 1 ); //Waits for conversion to finish

	uint16_t out = 0;
	out = ADCH<<sizeof(ADCL); //Move bit 9 & 10 to the left
	out |= ADCL; //Store the lower 8 bits

	return out;

}



/*
	Helper method to record connection status of all fans
	Turns on all unconnected channels and checks for new fan additions
*/
void checkConnections(void) {

	//TODO rewrite these segments to use universal logic

	/*
		----- FAN CHANNEL 1 -----
	*/

		//Check if this output has a newly connected fan
		if((connectedFans>>FAN1 & 1) != 0){

			//Check if there is any current draw with output on
			OCR0A = 255; //Turn on fan at full speed
			DDRD |= _BV(DDD5); //Turn on output
			_delay_us(UNCONNECTEDFANSTARTUPTIME); //Wait for output to turn on
			fan1Current = readFanCurrent(FAN1CH);

		} else {

			//TODO: match this with current timer status; otherwise, we might measure with output off!
			fan1Current = readFanCurrent(FAN1CH);
			
		}	

		if( fan1Current < CONNECTIONTHRESHOLD ){

			connectedFans &= ~(_BV(FAN1)); //unset bit
			OCR0A = 0; //Reset timer
			DDRD &= ~(_BV(DDD5)); //Turn off output
			
		}


	/*
		----- FAN CHANNEL 2 -----
	*/

		//Check if this output has a newly connected fan
		if((connectedFans>>FAN2 & 1) != 0){

			//Check if there is any current draw with output on
			OCR0B = 255; //Turn on fan at full speed
			DDRD |= _BV(DDD6); //Turn on output
			_delay_us(UNCONNECTEDFANSTARTUPTIME); //Wait for output to turn on
			fan2Current = readFanCurrent(FAN2CH);

		} else {

			//TODO: match this with current timer status; otherwise, we might measure with output off!
			fan2Current = readFanCurrent(FAN2CH);
			
		}	

		if( fan2Current < CONNECTIONTHRESHOLD ){

			connectedFans &= ~(_BV(FAN2)); //unset bit
			OCR0B = 0; //Reset timer
			DDRD &= ~(_BV(DDD6)); //Turn off output
			
		}


	/*
		----- FAN CHANNEL 3 -----
	*/

		//Check if this output has a newly connected fan
		if((connectedFans>>FAN3 & 1) != 0){

			//Check if there is any current draw with output on
			OCR1AL = 255; //Turn on fan at full speed
			DDRB |= _BV(DDB1); //Turn on output
			_delay_us(UNCONNECTEDFANSTARTUPTIME); //Wait for output to turn on
			fan3Current = readFanCurrent(FAN3CH);

		} else {

			//TODO: match this with current timer status; otherwise, we might measure with output off!
			fan3Current = readFanCurrent(FAN3CH);
			
		}	

		if( fan3Current < CONNECTIONTHRESHOLD ){

			connectedFans &= ~(_BV(FAN3)); //unset bit
			OCR1AL = 0; //Reset timer
			DDRB &= ~(_BV(DDB1)); //Turn off output
			
		}


	/*
		----- FAN CHANNEL 4 -----
	*/

		//Check if this output has a newly connected fan
		if((connectedFans>>FAN4 & 1) != 0){

			//Check if there is any current draw with output on
			OCR1BL = 255; //Turn on fan at full speed
			DDRB |= _BV(DDB2); //Turn on output
			_delay_us(UNCONNECTEDFANSTARTUPTIME); //Wait for output to turn on
			fan4Current = readFanCurrent(FAN4CH);

		} else {

			//TODO: match this with current timer status; otherwise, we might measure with output off!
			fan4Current = readFanCurrent(FAN4CH);
			
		}	

		if( fan4Current < CONNECTIONTHRESHOLD ){

			connectedFans &= ~(_BV(FAN4)); //unset bit
			OCR1BL = 0; //Reset timer
			DDRB &= ~(_BV(DDB2)); //Turn off output
			
		}


	/*
		----- FAN CHANNEL 5 -----
	*/

		//Check if this output has a newly connected fan
		if((connectedFans>>FAN5 & 1) != 0){

			//Check if there is any current draw with output on
			OCR2A = 255; //Turn on fan at full speed
			DDRB |= _BV(DDB3); //Turn on output
			_delay_us(UNCONNECTEDFANSTARTUPTIME); //Wait for output to turn on
			fan5Current = readFanCurrent(FAN5CH);

		} else {

			//TODO: match this with current timer status; otherwise, we might measure with output off!
			fan5Current = readFanCurrent(FAN5CH);
			
		}	

		if( fan5Current < CONNECTIONTHRESHOLD ){

			connectedFans &= ~(_BV(FAN5)); //unset bit
			OCR2A = 0; //Reset timer
			DDRB &= ~(_BV(DDB3)); //Turn off output
			
		}

}


/* ------------------------

[LED functions]

--------------------------- */
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

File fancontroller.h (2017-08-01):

#ifndef HEADER_FILE
#define HEADER_FILE

	//Includes
	#include <avr/io.h>
	#include <avr/interrupt.h>
	#include <avr/eeprom.h>
	#include <util/delay.h>

	//General functions
	void setup(void);
	void startup(void);

	//Fan functions
	uint16_t readFanCurrent(uint8_t channel);
	void checkConnections(void);

	//Display functions
	void refreshDisplay(void);
	uint8_t copyToBuffer(uint8_t LED);
	void setColour(uint8_t led, uint8_t redCh, uint8_t greenCh, uint8_t blueCh);
	void setAllColours(uint8_t redCh, uint8_t greenCh, uint8_t blueCh);
	void setColourType(uint8_t led, uint8_t colour[3]);
	void setAllColoursToType(uint8_t colour[3]);
	void shiftout(uint32_t input);

	//Interface Function
	void updateInterface(void);
	void parseInput(void);

	//View controllers (as functions #Yolo)
	void startController(void);
	void settingsController(void);
	void setfanController(void);
	void colouroverviewController(void);
	void coloursettingController(void);
	void colourchannelsettingController(void);

	//Debug controllers
	void debuginputController(void);
	void debugdisplayController(void);

	//Input functions
	void checkButton(uint8_t buttonStatus, uint8_t buttonTimer);

	//PORT LOCATIONS
		//Shift registry
			// Location of: SHIFTREG PORTD
			// Location of: SER PORTD0
			// Location of: SRCLK PORTD1
			// Location of: _SRCLR_ PORTD2
			// Location of: RCLK PORTD3
			// Location of: _OE_ PORTD4

		//LED refresh interrupt
			// Location of: REFRESHPORT PORTD
			// Location of: REFRESHPIN PORTD7

		//Fans' PWM channels
			// Location of: FAN1PWM OCR0A / P11 / PD5
			// Location of: FAN2PWM OCR0B / P12 / PD6
			// Location of: FAN3PWM OCR1A / P15 / PB1
			// Location of: FAN4PWM OCR1B / P16 / PB2
			// Location of: FAN5PWM OCR2A / P17 / PB3

	//Debugging switches - only one at the time!
	#define DEBUGINPUT 0
	#define DEBUGDISPLAY 0

	//Startup timings
	#define STARTUPFANWARMINGPERIOD 4000
	#define STARTUPFANWARMINGINDICATORINTERVAL 250

	//Timing functions
	#define WDTTIMOUT 16

	#define DEBOUNCETURN 150 
	#define DEBOUNCEBUTTON 250


	//Storage of fan status
	#define FAN1 0
	#define FAN2 1
	#define FAN3 2
	#define FAN4 3
	#define FAN5 4

	//Fans' analog channels
	#define FAN1CH 1
	#define FAN2CH 2
	#define FAN3CH 3
	#define FAN4CH 4
	#define FAN5CH 5

	//Minimum current reading to identify active fan
	#define CONNECTIONTHRESHOLD 20
	//Upper current bound allowed. Controls that no short or still fans are present.
	#define UPPERCURRENTTHRESHOLD 800
	//Waiting time in µs between unconnected output is turned on and current reading
	#define UNCONNECTEDFANSTARTUPTIME 50

	//Fan profile constants
	#define LPROFILE 0
	#define MPROFILE 1
	#define HPROFILE 2

	//Colour synonyms
	#define RED 0
	#define GREEN 1
	#define BLUE 2
	#define DIMMER 3 //DEPRACTED!

	#define MAXCHANNELVALUE 5

	#define REDLEDSHIFT 1
	#define GREENLEDSHIFT 1
	#define BLUELEDSHIFT -1

	//Number of unused bits at the end of the shit registry chain
	#define SHIFTREGISTEREMPTYBITS 2

	//Synonyms for LED's - these are in the opposite direction to index!
	#define LED01 9
	#define LED02 8
	#define LED03 7
	#define LED04 6
	#define LED05 5
	#define LED06 4
	#define LED07 3
	#define LED08 2
	#define LED09 1
	#define LED10 0

	#define PRIMARYCOLOUR 0
	#define COMPLEMENTCOLOUR 1
	#define SELECTCOLOUR 2

	#define RCH 0
	#define GCH 1
	#define BCH 2

	//Interface view status
	#define VIEWSTART 0
	#define VIEWSETTINGS 1
	#define VIEWSETFAN 2
	#define VIEWCOLOUROVERVIEW 3
	#define VIEWCOLOURSETTING 4
	#define VIEWCOLOURCHANNELSETTING 5

	#define LONGPRESSFORCOLOURDELAY 310

	//Input references
	#define DOWN 0
	#define LEFT 1
	#define RIGHT 2

	//Cursor location unknown value
	#define CURSORUNDETERMINED 100

#endif

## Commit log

2016-09-14 Added v1.1 version of schematics
    [Fan Controller.kicad_pcb, Fan Controller.sch, Fan control.sch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]
2016-09-14 Change rotary encoder to GND ref
    [Fan Controller.sch]
2016-09-14 Small routing change
    [Fan Controller.sch]
2016-09-14 Add ADC filter and ref
    [Fan Controller.sch, Fan control.sch, LED control.sch]
2016-09-14 Update component values
    [Fan Controller.sch]
2016-09-14 Add cap to AREF
    [Fan Controller.sch]
2016-09-14 Basic fuse config
2016-09-14 Update Timer1 to run in 8-bit mode
2016-09-14 Created empty Timer0 overflow vector for LED
2016-09-14 Add LED update logic
2016-09-14 Let unconnected pins float
    [Fan Controller.sch]
2016-09-14 Moved to software interrupt for LED refresh
2016-09-14 Add fuse settings
2016-09-14 shiftout is implemented, with test case
2016-09-15 Minor bugfix in shiftout, start on refreshDisplay
    Some variables were erroneously defined for shitfout, along with some
    registers.
    refreshDisplay-methods is now a bit more correct (it will output
    somethings). However, the code needs more review before it is ready.
    There is also a lot of flickering right now, which is not looking good...
    [fancontroller.c, fancontroller.h]
2016-09-16 Fixed minor bug in display updating
    [fancontroller.c]
2016-09-16 Added rotary encoder w. calibrated debounce
2016-09-16 PWM functionality now working
2016-09-16 Adjusted analog reading of fan current
2016-09-16 Now PWM turns off when no fan present
    The checkConnection method now disables the output registires for the pwm
    pins which are deemed to be unconnected. This will allow the pin current
    to be 0; otherwise, there is a small leakage current from the pins.
    [fancontroller.c, fancontroller.h]
2016-09-16 Update checkConnection to poll current
    Previously, the method used the existing pre-current reading. This new
    method is a bit better form, as the method is no longer relying on an
    external process updating the current readings!
    In addition, some Makros were inserted
    [fancontroller.c]
2016-09-16 Fix bug where new current values were not stored
    [fancontroller.c]
2016-09-16 Gather fan-related macros
2016-09-22 Add an experimental feature to Gamma-correct LED
    There was previously an issue with intensities of the LED's not changing
    noticably enough. An atempt has been made here to adjust this issue, by
    mapping the linear intensities to Gamma corrected ones.
    As there are only 8 values per channel, this was done via a lookup array.
    This features is expterimental as of this time, and needs to be tested.
    [fancontroller.c]
2016-09-29 Fixed wrong prefix on capacitors
    [Fan Controller.sch]
2016-10-22 Add 3D printing parts
    [Fan Controller - V1.skp, Fan Controller.skp, Fan controller Front v1.stl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]
2016-12-09 Update 3D-drawing
    [Back support.stl, Fan Controller.skp]
2016-12-10 Update schematic to v1.3
    [Fan Controller.sch, Fan control.sch, LED control.sch]
2016-12-11 Some testing, savepoint for changing LED update cycle
2016-12-11 Reduce gamma-significance & add luminance shift to LED
2016-12-11 LED calibration
2016-12-11 One more colour intensity level + calibration
2016-12-12 Longer and more flexilbe fan starup routine
2016-12-19 Add start colour to all LEDs
2017-01-22 Remove dimmer channel
    The dimmer channel couldn't be practically realized within the working
    parameters of the unit. The refresh rate of the LED panel is not
    sufficient to allow dimming without severe flickering issues.
    Refresh conditions and method signatures updated to follow this new
    path.
    [fancontroller.c, fancontroller.h]
2017-01-22 Set up watchdog timer and pin change interrupts
    Pin change interrupts on PCINT1 & PCINT2 used for rotary encoder inputs.
    The watchdog timer is used for timekeeping - specifically for timing
    debounces for the interrupts. This enables a less computationally taxing
    approach to parsing user inputs.
2017-01-31 Add views for setting fan & colour
    Implemented the view part of interface. This is not in charge of
    updating any values, only for displaying what is currently stored in the
    active variables.
2017-01-31 Add base input handling, and some debug functions
    Add an untested input handler, which parses the physical inputs from the
    rotary encoder. This includes a software debounce function.
    Also started to implement some of the view controllers, which will
    govern how the interface responds to user input. Currently, they are
    untested and only a couple are implemented.
    A possible problem is how the hand-off is to take place between the
    different controllers, without the previous inputs being interpreted
    as new ones. Probably, another tracking variable can be used, where we
    record if the input has been used for anything.
    Furthermore, I have added some debuging functions, so that the rotary
    encoder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
    [fancontroller.c, fancontroller.h]
2017-02-03 Add controller for fan settings
2017-02-03 Add controller for individual fan speed setting
